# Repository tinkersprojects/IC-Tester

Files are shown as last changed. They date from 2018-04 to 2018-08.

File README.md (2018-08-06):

# IC Tester
[https://tinkersprojects.com/](https://tinkersprojects.com/)

This is an IC tester for any type of logic chip. The device pules every pin combination and reads the all other pins to find which type of chip it is. The chip would have been already analysed before testing.

To read a 28 pin chip would take about 1/2 days and Thisbe is why I made the device be able to select the number pins of the chip to Be Tested. The larger the number of pins the slower it will read.

The device USB a sheld that attaches to an Arduino mega development board. The sheld has an LCD, SD and a user interface as well as the chip reader. To test the chip, the device uses 5v from the Arduino.

The PCB can be purchased from https://tinkersprojects.com/product/ic-tester/

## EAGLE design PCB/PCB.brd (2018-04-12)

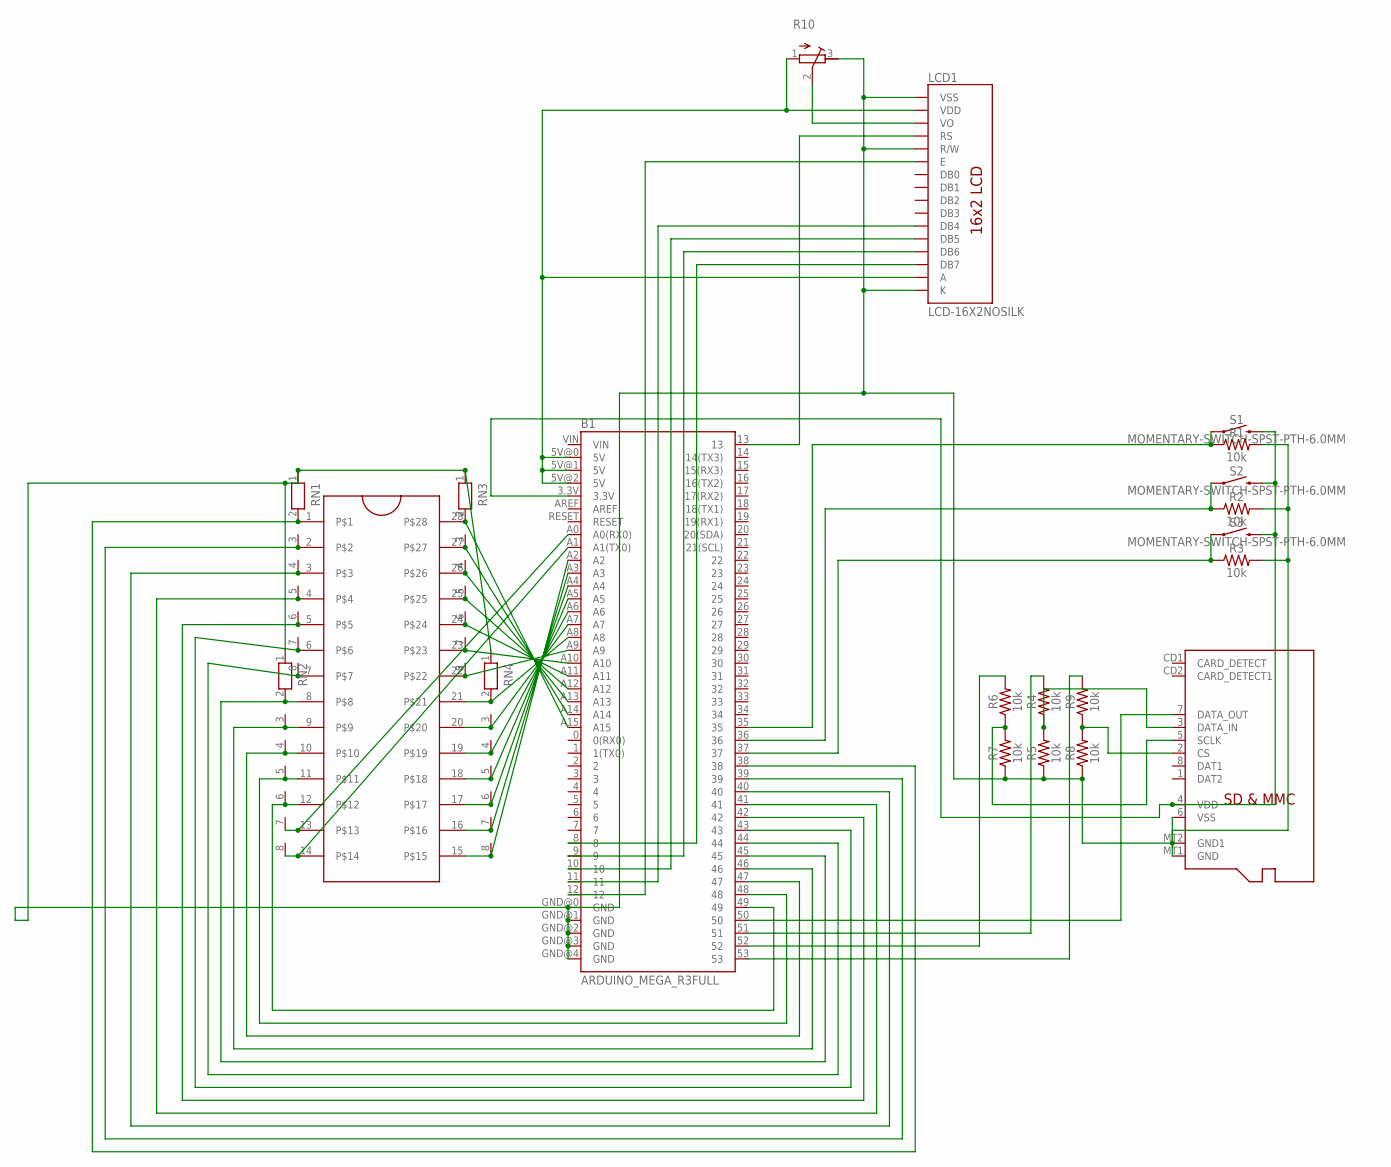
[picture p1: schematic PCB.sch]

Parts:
B1: ARDUINO_MEGA_R3FULL; ARDUINO_MEGA
LCD1: LCD-16X2NOSILK; LCD-16X2_NOSILK
R1, R2, R3, R4, R5, R6, R7, R8, R9: 10k; AXIAL-0.3
R10: R-TRIMM3339P; RTRIM3339P
RN1, RN2, RN3, RN4: RN07; RN-8
S1, S2, S3: MOMENTARY-SWITCH-SPST-PTH-6.0MM; TACTILE_SWITCH_PTH_6.0MM
U$1: MICROSD
U$2: ZIFSOCKET-28-3ZIFFSOCKET-28-3; DIL28-3-ZIF_SOCKET

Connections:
unnamed: B1.A15, RN3.2, U$2.28
unnamed: B1.A14, RN3.3, U$2.27
unnamed: B1.A13, RN3.4, U$2.26
unnamed: B1.A12, RN3.5, U$2.25
unnamed: B1.A11, RN3.6, U$2.24
unnamed: B1.A10, RN3.7, U$2.23
unnamed: B1.A9, RN3.8, U$2.22
unnamed: B1.A8, RN4.2, U$2.21
unnamed: B1.A7, RN4.3, U$2.20
unnamed: B1.A6, RN4.4, U$2.19
unnamed: B1.A5, RN4.5, U$2.18
unnamed: B1.A4, RN4.6, U$2.17
unnamed: B1.A3, RN4.7, U$2.16
unnamed: B1.A2, RN4.8, U$2.15
unnamed: B1.A1 (A1(TX0)), RN2.8, U$2.14
unnamed: B1.A0 (A0(RX0)), RN2.7, U$2.13
unnamed: B1.49, RN2.6, U$2.12
unnamed: B1.48, RN2.5, U$2.11
unnamed: B1.47, RN2.4, U$2.10
unnamed: B1.46, RN2.3, U$2.9
unnamed: B1.45, RN2.2, U$2.8
unnamed: B1.44, RN1.8, U$2.7
unnamed: B1.43, RN1.7, U$2.6
unnamed: B1.42, RN1.6, U$2.5
unnamed: B1.41, RN1.5, U$2.4
unnamed: B1.40, RN1.4, U$2.3
unnamed: B1.39, RN1.3, U$2.2
unnamed: B1.38, RN1.2, U$2.1
unnamed: B1.37, R3.P$1 (1), S3.1
unnamed: B1.5V@0 (5V), B1.5V@1 (5V), B1.5V@2 (5V), LCD1.2 (VDD), LCD1.15 (A), R10.1 (A)
unnamed: R6.P$1 (1), R7.P$2 (2), U$1.5 (SCLK)
unnamed: R8.P$2 (2), R9.P$1 (1), U$1.2 (CS)
unnamed: LCD1.3 (VO), R10.2 (S)
unnamed: B1.50, U$1.7 (DATA_OUT)
unnamed: R4.P$1 (1), R5.P$2 (2), U$1.3 (DATA_IN)
unnamed: B1.51, R4.P$2 (2)
unnamed: B1.53, R9.P$2 (2)
unnamed: B1.52, R6.P$2 (2)
unnamed: B1.13, LCD1.4 (RS)
unnamed: B1.12, LCD1.6 (E)
unnamed: B1.11, LCD1.11 (DB4)
unnamed: B1.10, LCD1.12 (DB5)
unnamed: B1.9, LCD1.13 (DB6)
unnamed: B1.8, LCD1.14 (DB7)
unnamed: B1.36, R2.P$1 (1), S2.1
unnamed: B1.35, R1.P$1 (1), S1.1
VDD: B1.3.3V, S1.3 (2), S2.3 (2), S3.3 (2), U$1.4 (VDD)
VSS: B1.GND@0 (GND), B1.GND@1 (GND), B1.GND@2 (GND), B1.GND@3 (GND), B1.GND@4 (GND), LCD1.1 (VSS), LCD1.5 (R/W), LCD1.16 (K), R1.P$2 (2), R2.P$2 (2), R3.P$2 (2), R5.P$1 (1), R7.P$1 (1), R8.P$1 (1), R10.3 (E), RN1.1, RN2.1, RN3.1, RN4.1, U$1.6 (VSS), U$1.MT1 (GND), U$1.MT2 (GND1)

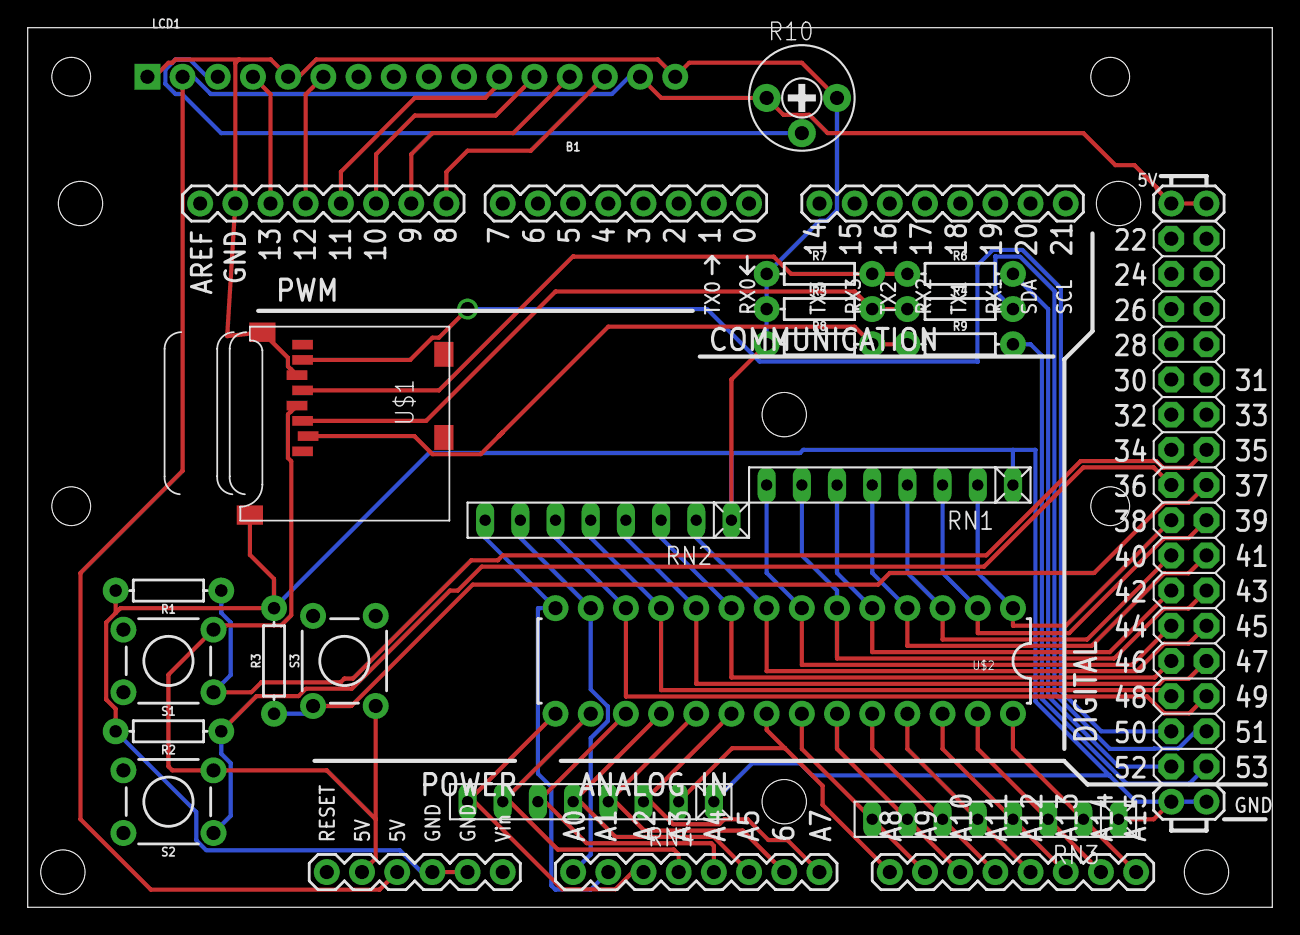
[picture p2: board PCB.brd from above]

Board: 2 copper layers, 89.8 x 63.5 mm, 21 parts (0 on the bottom side), 48 nets.

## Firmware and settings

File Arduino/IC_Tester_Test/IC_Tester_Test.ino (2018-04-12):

#include <LiquidCrystal.h>
#define StartButtonPin 37
#define downButtonPin 36
#define upButtonPin 35

byte testpins[28] = {38,39,40,41,42,43,44,45,46,47,48,49,54,55,56,57,58,59,60,61,62,63,64,65,66,67,68,69};
unsigned long test[28];// = {};

LiquidCrystal lcd(13, 12, 11, 10, 9 , 8);

byte numberofpins = 2;

void setup() 
{
  lcd.begin(16, 2);
  Serial.begin(115200);
  pinMode(StartButtonPin, INPUT);
  pinMode(upButtonPin, INPUT);
  pinMode(downButtonPin, INPUT);

  reset();

  lcd.setCursor(0,0);
  lcd.print("Pins: ");
  lcd.print(numberofpins);
  lcd.print("  ");
}

void loop() 
{
  if(pressedbutton(upButtonPin) == HIGH)
  {
    if(numberofpins>=28)
    {
      numberofpins=2;
    }
    else
    {
      numberofpins = numberofpins + 2;
    }
    lcd.setCursor(0,0);
    lcd.print("Pins: ");
    lcd.print(numberofpins);
    lcd.print("  ");
  }

  if(pressedbutton(downButtonPin) == HIGH)
  {

    if(numberofpins<=2)
    {
      numberofpins=28;
    }
    else
    {
      numberofpins = numberofpins - 2;
    }
    lcd.setCursor(0,0);
  lcd.print("Pins: ");
    lcd.print(numberofpins);
    lcd.print("  ");
  }

  if(pressedbutton(StartButtonPin) == HIGH)
  {
    reset();
    lcd.clear();
    lcd.print("START"); 

    unsigned long totalnumber = powerof(numberofpins);
    for(unsigned long i = 0; i<totalnumber;i++)
    {
      unsigned long Value = GetValue(i);
      if(Value > i)
      {
        Serial.print(i);
        Serial.print(" ");
        Serial.print(Value);
        Serial.println();
        lcd.setCursor(0,1);
        lcd.print(i);
        lcd.print(" ");
        lcd.print(Value);
      }
    }
    Serial.println("DONE");
    lcd.clear();
    lcd.setCursor(0,0);
    lcd.print("Pins: ");
    lcd.print(numberofpins);
    lcd.print("  ");
    lcd.print("DONE"); 
    lcd.setCursor(0,1);
  }
}



bool pressedbutton(byte pin)
{
  if(digitalRead(pin) == HIGH)
  {
    while(digitalRead(pin) == HIGH){}
    return true;
  }
  return false;
}


unsigned long powerof(unsigned int power)
{
  unsigned long result = 1;
  for(unsigned long i = 1; i<=power;i++)
  {
    result = result * 2;
  }
  return result;
}




void reset()
{
  for(int i = 0; i<sizeof(testpins);i++)
  {
    pinMode(testpins[i], INPUT);
  }
}




unsigned long GetValue(unsigned long N)
{
  int j = 0;
  for(int i = 0; i<numberofpins;i++)
  {
    if(numberofpins/2<i)
    {j=i;}
    else
    {j=sizeof(testpins)-numberofpins+i;}

    if((N >> i) & 1)
    {
      pinMode(testpins[j], OUTPUT);
      digitalWrite(testpins[j],HIGH);
      Serial.print(1);
    }
    else
    {
      digitalWrite(testpins[j],LOW);
      pinMode(testpins[j], INPUT);
      Serial.print(0);
    }
  }

  Serial.print(" ");
  
  unsigned long result = 0;

  for(int i = 0; i<numberofpins;i++)
  {
    if(numberofpins/2<i)
    {j=i;}
    else
    {j=sizeof(testpins)-numberofpins+i;}
    
  Serial.print(digitalRead(testpins[j]));
  
    if(digitalRead(testpins[j]) == HIGH)
    {
      result += powerof(i);
    }
  }
  Serial.print(" ");
  return result;
}

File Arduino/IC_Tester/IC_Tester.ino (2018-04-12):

#define StartButtonPin 3

byte testpins[28];// = {};
unsigned long test[28];// = {};

void setup() 
{
  Serial.begin(115200);
  pinMode(StartButtonPin, INPUT);

  reset();
}

void loop() 
{
  if(digitalRead(StartButtonPin) == HIGH)
  {
    reset();
    Serial.println("START");
    for(unsigned long i = 0; i<268435456;i++)
    {
      Serial.print(i);
      Serial.print(":");
      Serial.println(GetValue(i));
    }
  }
}




void reset()
{
  for(int i = 0; i<testpins.count;i++)
  {
    pinMode(testpins[i], INPUT);
  }
}




unsigned long GetValue(unsigned long N)
{
  for(int i = 0; i<testpins.count;i++)
  {
    if((N >> i) & 1)
    {
      pinMode(testpins[i], OUTPUT);
      digitalWrite(testpins[i],HIGH);
    }
    else
    {
      digitalWrite(testpins[i],LOW);
      pinMode(testpins[i], INPUT);
    }
  }

  unsigned long result = 0;

  for(int i = 0; i<testpins.count;i++)
  {
    if(!((N >> i) & 1) && digitalRead(testpins[i])== HIGH)
    {
      result = result |= 1 << i;
    }
  }
  return result;
}

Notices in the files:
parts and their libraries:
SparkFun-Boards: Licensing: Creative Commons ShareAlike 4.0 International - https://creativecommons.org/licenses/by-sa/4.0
